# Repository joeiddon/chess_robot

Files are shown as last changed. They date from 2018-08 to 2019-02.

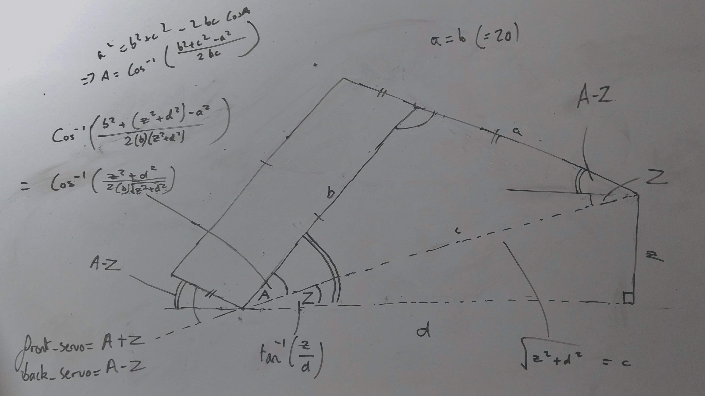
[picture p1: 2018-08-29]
calculations.jpg

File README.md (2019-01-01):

# Source for a full *chess-playing* robot.

*Note that this project is not finished.*

File/Directory|Purpose
----|---
[sketch/sketch.ino](sketch.ino)|Sketch for the Aruino Nano that controls the arm.
[vision.py](vision.py)|A (partial) computer vision library using `numpy` - only minimal functions.
[recognition.py](recognition.py)|Using `vision.py`, detects the locations of the pieces and identies their colours.
[tkinter_controller.py](tkinter_controller.py)|A GUI written with TKinter for controlling the robot arm.
[intelligence/](intelligence)|An AI written in C for finding the best chess move using [`negamax`](https://en.wikipedia.org/wiki/Negamax).
[model/](model)|Contains `.stl` and `.scad` designs for the 3d printed arm.

See some videos of the arm in progress here:

https://photos.app.goo.gl/uKwEp8JHDU8QnPrb8

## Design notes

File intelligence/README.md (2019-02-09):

chess_ai
========================

#### A Chess AI written in pure C. [work in progress]

An AI was originally written for this project in Python, however I made the mistake of describing my board state via a list which of course is mutable. As a result, I was forced to make lots of copies of the board state which severely reduced the speed of computation; resulting in an easily beatable player. Thus, I decided to start again from scratch at a lower level. This is that attempt.

---

### Navigating the Source

The code is split up into three `.c` source files: **`main.c`**, **`core.c`** and **`helpers.c`**.

 - The `main()` function is appropriately located in `main.c` and at the time of writing, merely has some different tests that can be commented in or out.
 - The `core.c` file contains the most algorithmically and computationally heavy functions (e.g. `generate_moves()` and `evaluate()`).
 - Handy functions, such as `display_state()` and `make_move()`, are found in `helpers.c`.

In addition to these, there are also three header files: **`common.h`**, **`core.h`** and **`helpers.h`**. The `common.h` header is `#include`d in every source file and contains `#define`s required by lots of functions and the main `struct`s. The `core.h` and `helpers.h` files are only included in their respective `.c` source files and the `main.c` source file.

---

### Compilation and Usage

To compile, use the following command.

```
gcc *.c -o chess_ai
```

The program can then be run with: `./chess_ai`.

---

### Code Explanation:

There are two main types (structures): `state_t` and `move_t` used throughout the code. (I appended the `_t` to make distinguish them from variable names).

In **`state_t`**, the state of the board is described by an `8` by `8` array of bytes (`int8_t`) named `pieces`. The array is described from white's perspective, with `(0,0)` at white's left castle. The magnitude of each element in the array determines the piece type, e.g. a bishop is represented by a `4` and the sign represents the side, positive for white and negative for black. An empty square is delineated by a zero. Their is also a member called `invalid_castles` which is a byte (`uint8_t`). It encodes which of the four possible castling moves are valid through its four least significant bits. Then, using bit-wise operators I wrote three macros to manipulate this variables bits: `GET_BIT(x,i)`, `SET_BIT_HIGH(x,i)` and `SET_BIT_LOW(x,i)`. Using these, we can now read and write to this member - resulting in a memory-efficient method to store which castling moves are valid.

The **`move_t`** structure has five members: `from`, `to`, `piece_taken`, `is_pawn_promotion`, `castle` and `makes_castle_invalid`. The `from` and `to` members are byte arrays (`uint8_t`), each of length 2. They hold the coordinates of the position the piece moved was picked up from, and placed at, respectively. The `piece_taken` member is a signed byte representing the piece taken with that move, if the move does result in a piece being taken, otherwise it holds `0`. This is required for the `inverse_move()` function, so the correct piece can be put back on the board. The `is_pawn_promotion` member is merely a boolean whose meaning is evident from its name. This member is again necessary for the `inverse_move` function to distinguish between a queen being moved by one vertically onto the back row and a legit pawn promotion. The `castle` member depicts whether the move is a castle, with a `0` implying not, a `1` implying a kingside castle and a `2` implying a queenside castle. Finally, the `makes_castle_invalid` member is a boolean representing if that move makes a castling no longer valid (illegal). You may ask: why is this necessary when you can just say in the `make_move()` function that whenever the king or a castle moves, the corresponding castle move(s) is/are now no longer valid? As before, this member is necessary for the `inverse_move()` function as in the case where the move describes a king or castle moving away from its home spot, it needs to be able to tell if this was the first move of that piece, or if it is merely a move later in the game when the piece re-visits the home spot. Hence, to be able to decide whether undoing this move makes it now legal to castle, the member is required to tell it if that specific move was the one that made it illegal (very long-winded, I know).

Now those two structures have been explained (in much detail), the code should be relatively easy to follow. Note that the `in_check` and `generate_moves` functions both use hacky macros, defined in `core.h`, that contain if-statements and `break` statements and span over multiple lines. They make those functions take at least half the line length they would be without them, but at the cost of making the code slightly unclear if you wish to follow what they do. Similarly, in the `make_move()` and `inverse_make()` functions, the macros `MOVE_TO` and `MOVE_FROM`, defined in `helpers.h`, make the code readable but are quite impure (hacky).

However, if I were to delve into the core of the code, I must explain the [Negamax algorithm](https://en.wikipedia.org/wiki/Negamax) and [Alpha-Beta pruning](https://en.wikipedia.org/wiki/Alpha%E2%80%93beta_pruning).

To explain negamax, un understanding of [minimax](https://en.wikipedia.org/wiki/Minimax) is required. This is an algorithm for deciding what is the best move to play in a given game. It works by depth-first searching the game tree, at each node, depending on whose turn it is, the algorithm tries to maximise or minimise the best score of all the moves that can be played from there. Since the game tree for chess cannot be traversed (the branching factor is `~30` and say that a game takes `~40` moves for each player, then there are `~30^80` possible states which is `~10^120` and there are only `~10^20` atoms in the observable universe), we must use an evaluation function to "rate" the current game position for a certain side once a given depth has been reached.

Negamax merely takes advantage of the fact that `max(x,y) = -min(-x,-y)`, so instead of having to write an if-statement to decide whether we should be maximising or minimising at a given stage, we can just always maximise the negative of the different move scores to decide our best move. This makes the basic algorithm really quite simple.

In pseudo-code:

```
If depth is 0:
    Return evaluation of current board

Otherwise...

Set our best move score to -infinity.
Loop through all possible moves
    Make that move
    If - opponents best score > best score:
        Set best move score to - opponents best score
        Set best move to current move
    Undo that move
End Loop

Return best move score
[...and somehow propagate up the corresponding best move]
```

Finally, there is room for a huge efficiency improvement. It's name, as previously mentioned, is alpha-beta pruning. I'll admit to it taking a while for me to fully understand its implementation but, with some thought, the following diagram should make it evident how certain portions of the tree can be "discounted" (not searched) - thus leading to less computation; allowing us to search to greater depths.

negamax and alpha-beta pruning image
*[source](https://commons.wikimedia.org/wiki/File:AB_pruning.svg)*

An example may also help. Say we have 2 moves to choose from: A and B. In doing move A, we see that our opponents best move ends up in us losing a pawn. Then mid-way though evaluating move B, we see that one of our opponents responses ends with us being a queen down. We now don't need to bother evaluating their other responses as we know that one of their replies results in an outcome worse than our current best outcome that we are assured of (just losing a pawn). Hence we don't need to evaluate these replies and can "prune" the game tree (all the two red lines in the diagram above).

Therefore, whenever we can assure that our best outcome is better than their best outcome (our worst), we can stop evaluating the current moves and return our best outcome.

This is coded by holding two variables: `alpha` and `beta` which represent our best and their best outcomes respectively. Then, we can say that whenever `alpha >= beta`, we can stop looping through our different moves (`break`/`return`). Since we are using negamax, when we pass these down to the next `negamax`, we must reverse them around - i.e. our best score is now the opponent's "opponent's best score" and their best score is now the opponent's "best score". Finally, we must negate both these values because they are trying to maximise their score.

This method leads to a major perfomance game. In the mid-game, the engine can search to depth `5` from the initial state in only about `1` second.

However, a very simple addition can be made to give us further advantages. This stems from the fact that the more of the tree we can prune earlier on, the faster are search is. We can prune more tree earlier on by doing some initial move ordering - taking a guess at what will be a good move. This function could be improved, but my current function `order_moves()` simply tells negamax which moves take pieces and which don't (very simple given our `move_t` data structure). Using this, these capture moves can be searched first - making prunes possible earlier.

The result of this initial move ordering is dramatic. It can now search to depth `6` from a complicated state (lots of captures, very congested) in just `1.5` seconds where the old algorithm took roughly `12` seconds for this!

My implementation for the negamax algorithm along with the simplistic `order_moves()` function can be found in **`core.c`**

### Limitations:

- No En-Passant.
- Auto queen-promotion for all pawns.
- No castling (I tried in [b5be2e8](https://github.com/joeiddon/chess_robot/commit/b5be2e8) but they're were so many bugs for little gain that I scrapped it).
- Get's into infinite loops when plays itself because no threefold repetition handling.

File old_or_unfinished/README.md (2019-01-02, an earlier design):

This sub-directory contains code that is not currently being used, but I am keeping to either:

- look back on for reference
- revisit in hope of completing it.

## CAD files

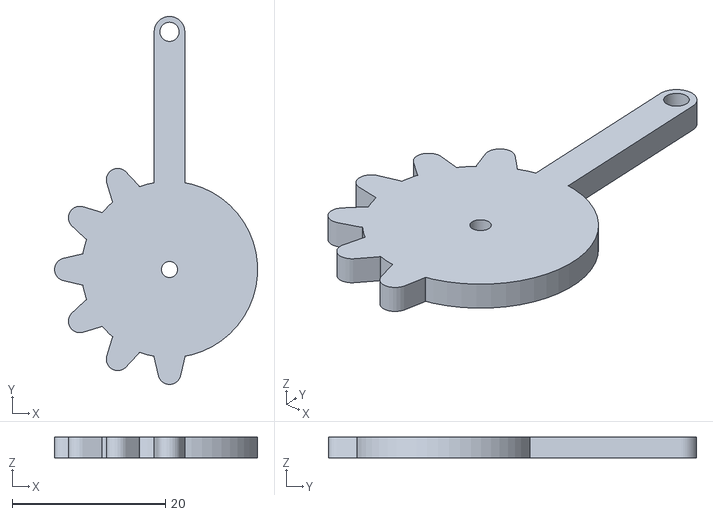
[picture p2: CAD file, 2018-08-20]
model/stls/gripper/right_gear.stl
26.5 x 48.0 x 2.70

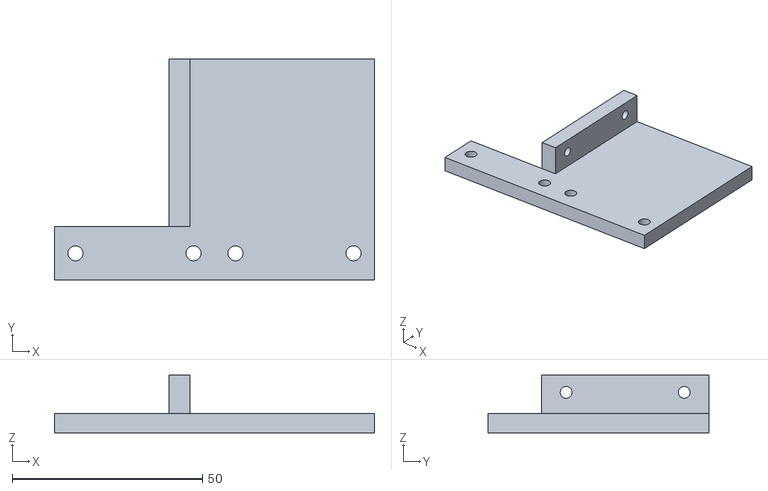
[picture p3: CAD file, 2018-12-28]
model/stls/stepper_plate.stl
84.0 x 58.0 x 15.1

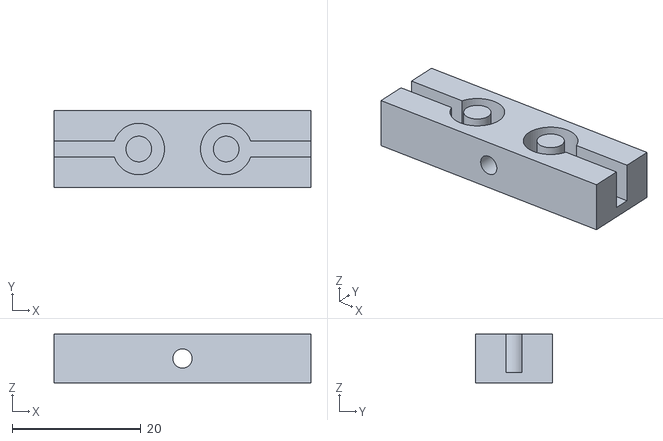
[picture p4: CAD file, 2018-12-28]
model/stls/belt_clamp.stl
40.0 x 12.0 x 7.60

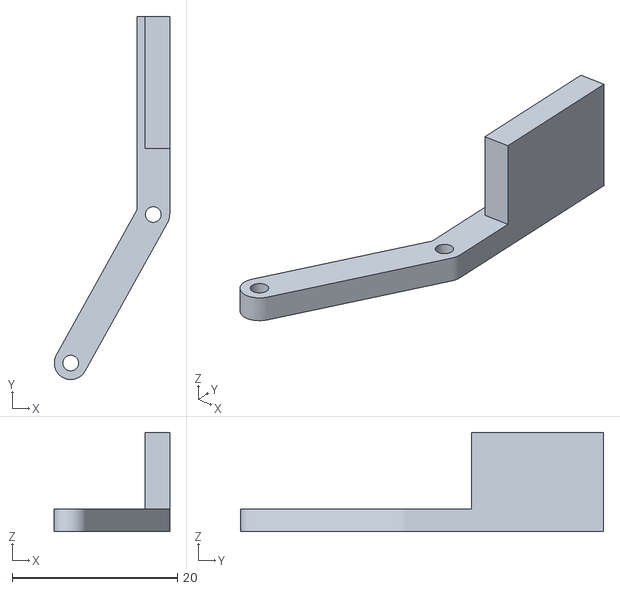
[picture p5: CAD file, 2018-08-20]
model/stls/gripper/left_arm.stl
14.0 x 44.0 x 12.0

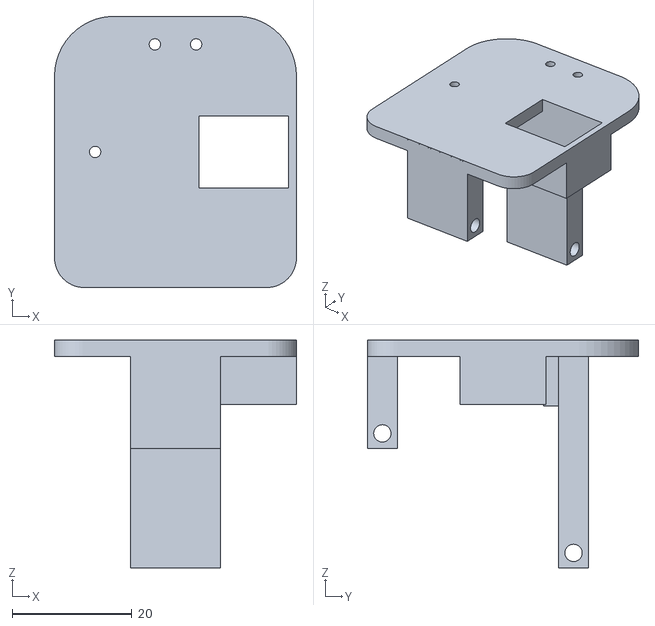
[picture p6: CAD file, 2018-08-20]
model/stls/gripper/bottom_plate.stl
40.5 x 45.4 x 38.1

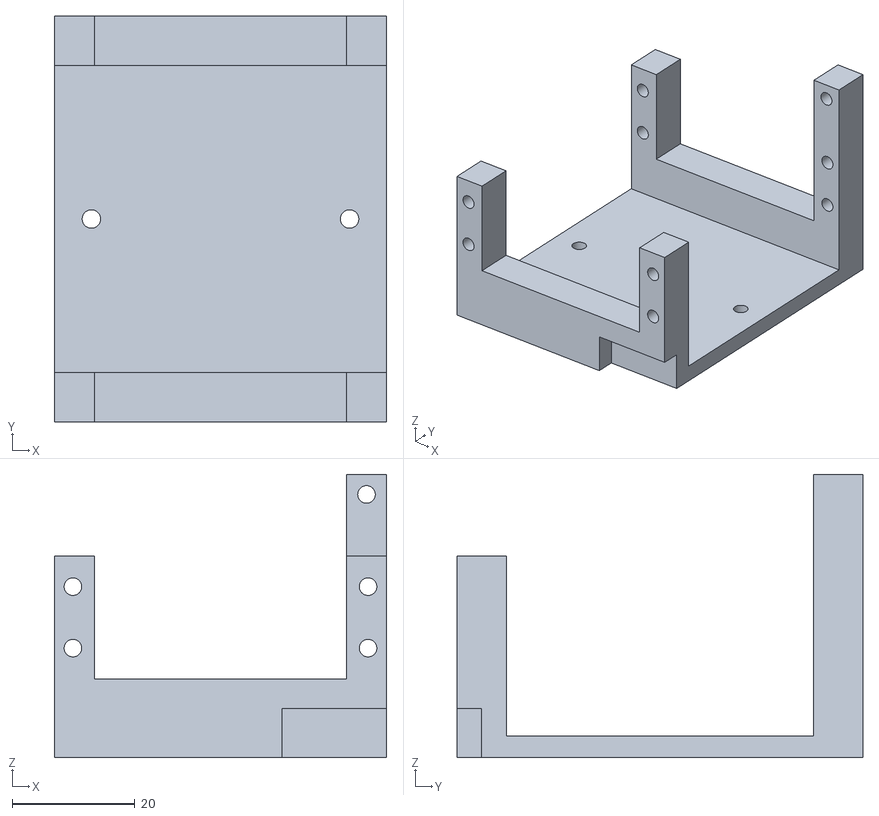
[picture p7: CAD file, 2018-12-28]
model/stls/plate.stl
54.0 x 66.0 x 46.0

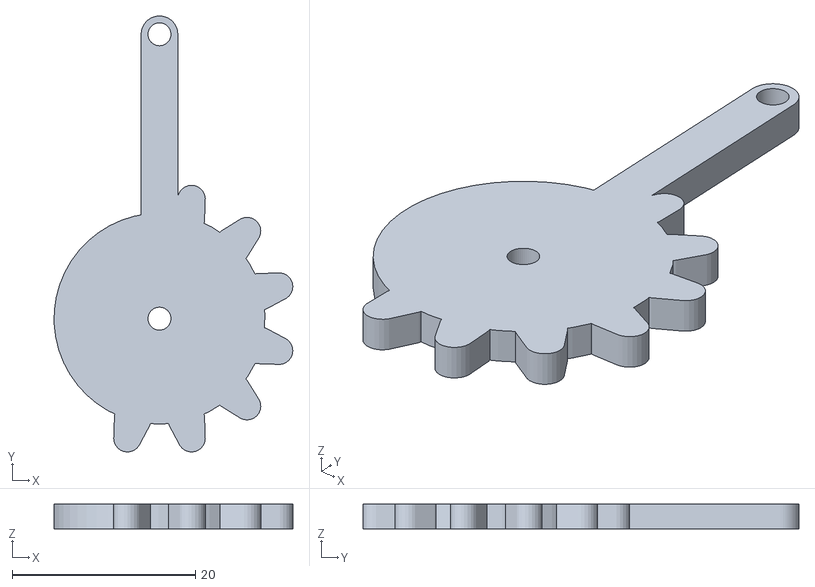
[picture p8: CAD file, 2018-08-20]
model/stls/gripper/left_gear.stl
26.0 x 47.5 x 2.70

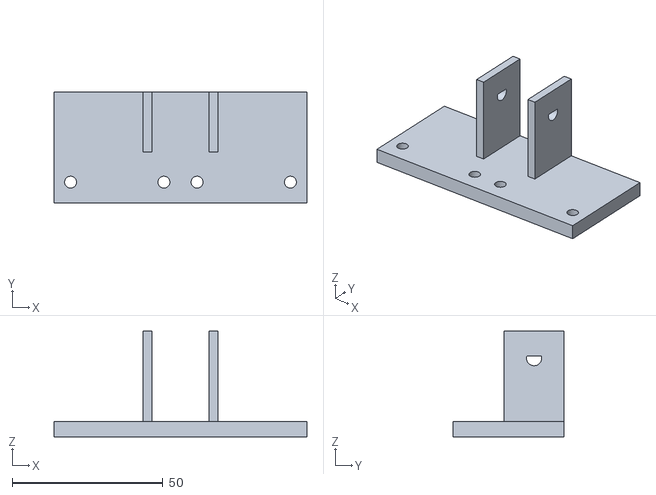
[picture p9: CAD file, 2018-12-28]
model/stls/pulley_plate.stl
84.0 x 37.0 x 35.1

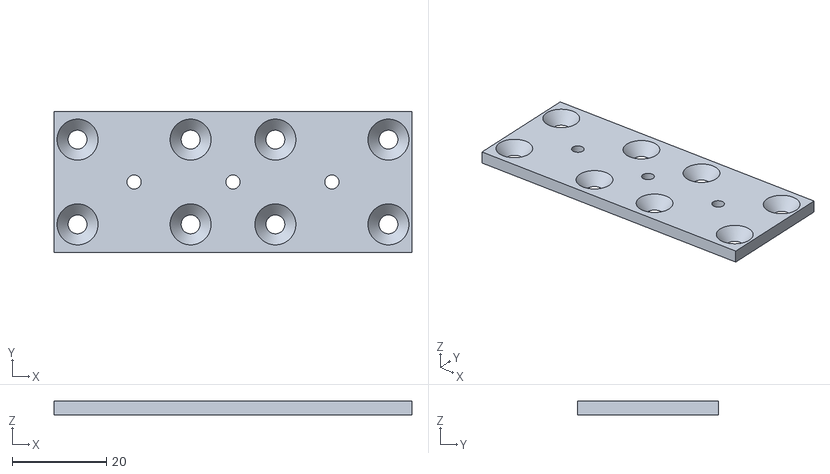
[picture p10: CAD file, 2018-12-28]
model/stls/bearing_plate.stl
76.0 x 30.0 x 3.00

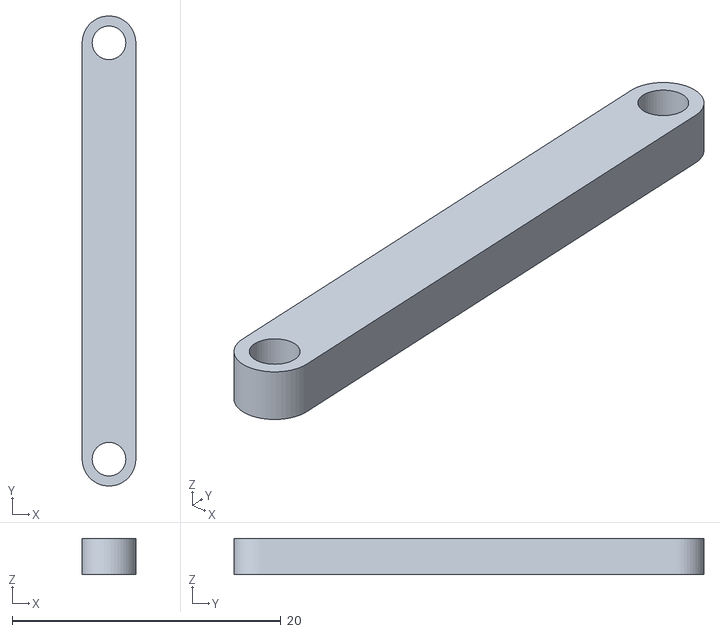
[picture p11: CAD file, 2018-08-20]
model/stls/gripper/beam.stl
4.00 x 35.0 x 2.70

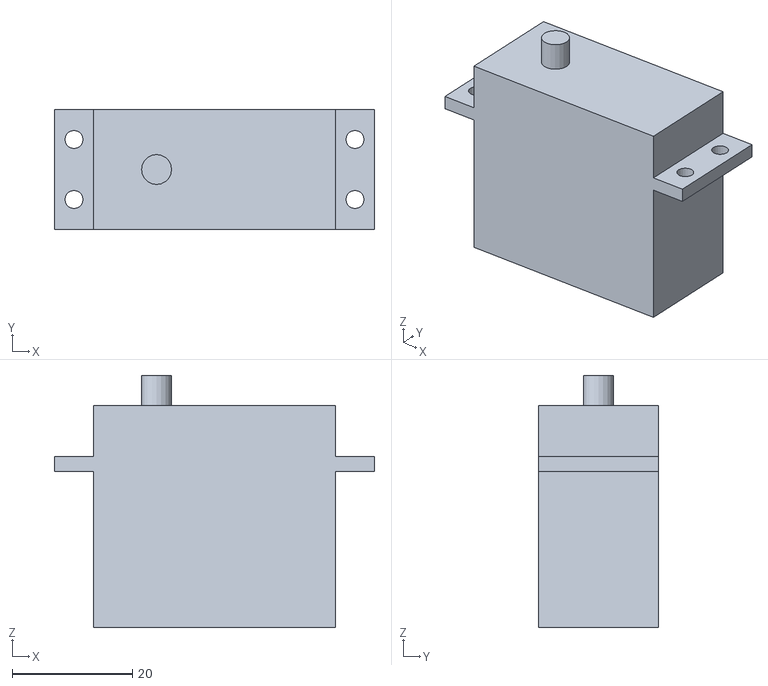
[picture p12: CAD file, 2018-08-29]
model/stls/mg996r.stl
53.3 x 20.0 x 42.0

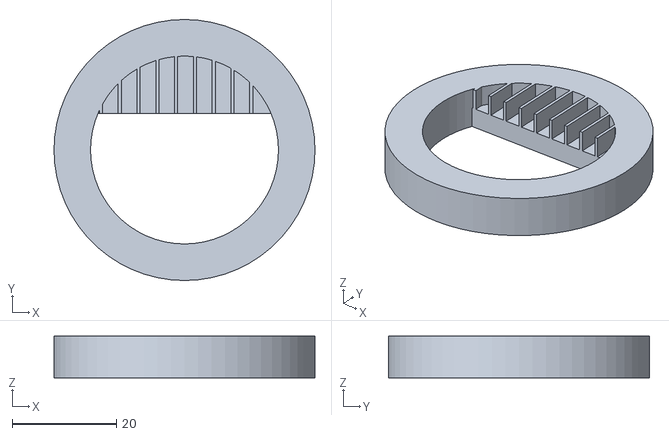
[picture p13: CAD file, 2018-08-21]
model/stls/ring.stl
50.0 x 50.0 x 8.00

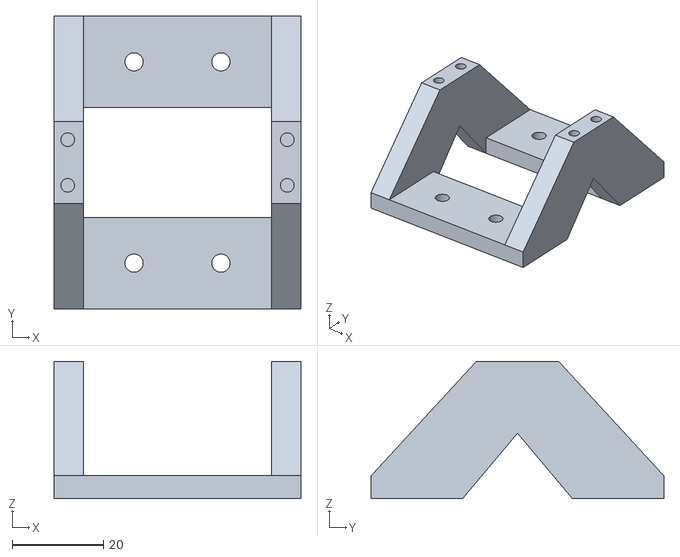
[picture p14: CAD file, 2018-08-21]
model/stls/base.stl
54.0 x 64.0 x 30.0

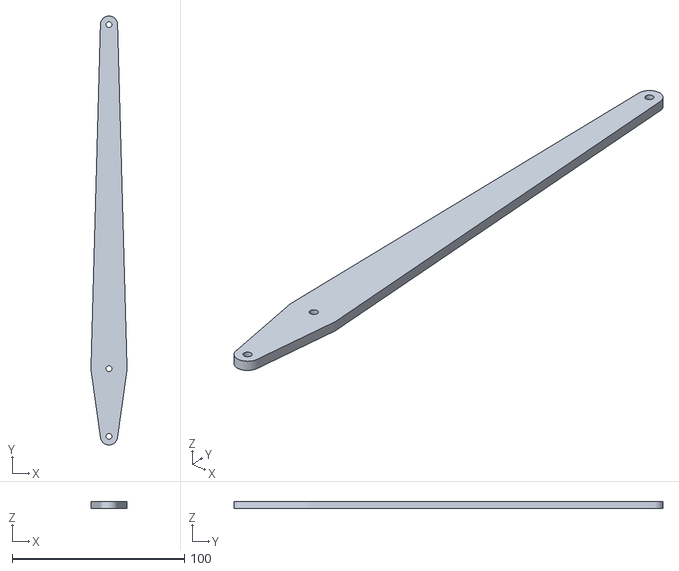
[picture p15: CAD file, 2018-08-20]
model/stls/link5.stl
21.0 x 249.4 x 3.90

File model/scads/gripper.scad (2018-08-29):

$fn = 50;
locked3mm = 2.9;           //hole diameter for a locked/tight/screwed down 2mm screw
free_turning2mm = 2.5;      //hole diameter for a free turning 2mm screw
locked2mm  = 1.9;            //hole diameter for a locked/tight/screwed down 2mm
thickness = 2.7;           //thickness of the gears and beams etc.
gear_radius = 15;           //radius of the gears (cogs)
left_gear_hole_diameter = free_turning2mm; //diameter of hole in left gear
right_gear_hole_diameter = 2.1;   //attacing to servo sotiny bit > 2mm (shrinkage)
no_teeth  = 7;              //number of teeth on the gears
teeth_width = 4;            //width of gear teeth
teeth_bevel = 3;            //diameter of circles at end of teeth
teeth_height = 3.5;         //height of gear teeth
teeth_budge = 0.4;         //distances gears need to be appart to fit together
beam_widths = 4;           //width of all beams
beam1_width = beam_widths;    //width of the first beam
beam1_length = 33;          //length of the first beam
beam1_hole_diameter = free_turning2mm; //diameter of screw hole at end of beam
beam2_width = beam_widths;   //width of the second beam
beam2_length = beam1_length; //length of the second beam
beam2_hole_diameter = free_turning2mm;//diameter of screw holes at end of beam
beam2_center_dist = 10;       //translating beam2 from beam1 towards the centerline
beam2_forward_dist = 18;     //translatimg beam2 from beam1 in y dir towards the grabber end
servo_width = 12;           //width of servo
servo_length = 23;          //length of servo
servo_height = 10.8;        //height of servo bracket (not whole servo)
servo_wall_thick = 1.2;      //thickness of bracket
servo_shaft = 5.9;          //distance of shaft from closest lengthwise edge
gripper_arm_length = 24;     //length of nipper
gripper_arm_thickness = 5;   //thickness of end nippers
gripper_arm_pad_length = 16;  //length of the raised pad
gripper_arm_pad_thickness = 3;//thickness of the raised pad
gripper_arm_pad_height = 12;  //height of the raised pad
gripper_arm_width = beam_widths; //width of end nippers

gear_hole_dist = gear_radius * 2 - teeth_height + teeth_budge;

//////

arm_block_width = 15;        //width of block for connecting arms
arm_block_length = 5;         //length ""
arm_block_height = 9.9 + 5.5;         //height for screws to attach to connecting arms

support_arm_length = 5;      //length of block
support_arm_width = 15;       //widhth of block
support_arm_height = arm_block_height + 20;     //heighrt for screw to attach to the support arm
support_arm_distance = 32;   //distance from little block
support_arm_stength_width  = 4;  //width of support for support arm block
support_arm_stength_length = 2.5; //length ""


plate_width = 40.5;           //width of bottom plate
plate_length = 40 + locked3mm + arm_block_length/2;          //length of bottom palte
plate_bevel_back = 5;        //bevel radius for back corners of plate
plate_bevel_front = 10;      //bevel radius for front corners of plate


module gear(){
   cylinder(r=gear_radius - teeth_height, h = thickness);
   for (i = [0:180/(no_teeth-1):180]){
      rotate(i)
      hull(){
         translate([0,-0.5*teeth_width,0])
         cube([gear_radius - teeth_height, teeth_width, thickness]);
         translate([gear_radius - teeth_bevel /2, 0, 0])
         cylinder(d = teeth_bevel, h=thickness, $fn = 25);
      }
   }
}


module left_gear(){
   difference(){
      union(){
         rotate(-(180/(no_teeth-1)) / 2 - 90)
         gear();
         beam1();
      }
      cylinder(d=left_gear_hole_diameter, h=thickness);
   }
}

module right_gear(){
   difference(){
      union(){
         rotate(90)
         gear();
         beam1();
      }
      cylinder(d=right_gear_hole_diameter, h=thickness);
   }  
}

module beam1(){
   difference(){
      union(){
         translate([-0.5 * beam1_width, 0, 0])
         cube([beam1_width, beam1_length - 0.5 * beam1_width, thickness]);
         translate([0, beam1_length - 0.5 * beam1_width, 0])
         cylinder(d=beam1_width, h=thickness);
      }
      translate([0, beam1_length - 0.5 * beam1_width, 0])
      cylinder(d=beam1_hole_diameter, h=thickness);
   }
}

module beam2(){
   difference(){
      union(){
         translate([-0.5 * beam2_width, 0, 0])
         cube([beam2_width, beam2_length - 0.5 * beam2_width, thickness]);
         cylinder(d=beam2_width, h=thickness);
         translate([0,beam2_length - 0.5 * beam2_width, 0])
         cylinder(d=beam2_width, h=thickness);   
      }
      cylinder(d=beam2_hole_diameter, h=thickness);
      translate([0, beam2_length - 0.5 *beam2_width, 0])
      cylinder(d=beam2_hole_diameter, h=thickness);      
   }
}

module bottom_plate(){
   difference (){
      //bottom base plate to cut crap out of
      hull(){
         translate([gear_hole_dist/2 - plate_width/2 + plate_bevel_front, plate_length/2 - plate_bevel_front, 0])
         cylinder(r=plate_bevel_front, h = thickness);
         translate([gear_hole_dist/2 + plate_width/2 - plate_bevel_front, plate_length/2 - plate_bevel_front, 0])
         cylinder(r=plate_bevel_front, h = thickness);
         translate([gear_hole_dist/2 - plate_width/2 + plate_bevel_back , -plate_length/2 + plate_bevel_back, 0])
         cylinder(r=plate_bevel_back, h = thickness);
         translate([gear_hole_dist/2 + plate_width/2 - plate_bevel_back , -plate_length/2 + plate_bevel_back, 0])
         cylinder(r=plate_bevel_back, h = thickness);
      }
      
      /*
      translate([-0.5 * plate_length + 0.5 * gear_hole_dist, -0.5 * plate_width, 0])
      cube([plate_length, plate_width, thickness]);
      */
      
      //holes for screws of gears and servo mount cutouts
      cylinder(d=locked2mm,h=thickness);
      translate([gear_hole_dist -2, 0, 0])
      cube([15, servo_width, 30], center=true);  
      
      //cutouts for beam 2 bottom hole mounts
      translate([beam2_center_dist, beam2_forward_dist, 0])
      cylinder(d=locked2mm, h=thickness);
      translate([gear_hole_dist - beam2_center_dist, beam2_forward_dist, 0])
      cylinder(d=locked2mm, h=thickness);
      
   }
   translate([gear_hole_dist, 0, -servo_height + thickness])
   servo_bracket();
   
   //arm block
   translate([gear_hole_dist / 2 - arm_block_width/2, -plate_length/2, -arm_block_height])
   difference(){
      cube([arm_block_width, arm_block_length, arm_block_height + arm_block_length/2]);
      translate([0, arm_block_length/2, arm_block_length/2 ])
      rotate([0, 90, 0])
      cylinder(d = locked3mm, h=arm_block_width);
   }
   
   //suport arm block
   translate([gear_hole_dist / 2 - support_arm_width/2, -plate_length/2 + arm_block_length/2 + support_arm_distance - support_arm_length/2, -support_arm_height])
   difference(){
      union(){
         cube([support_arm_width, support_arm_length, support_arm_height + support_arm_length/2]);
         translate([support_arm_width/2-support_arm_stength_width/2,-support_arm_stength_length,support_arm_length/2+ support_arm_height - servo_height])
         cube([support_arm_stength_width, support_arm_stength_length, servo_height]);
      }
      translate([0,support_arm_length/2, support_arm_length/2])
      rotate([0, 90, 0])
      cylinder(d=locked3mm, h = support_arm_width);
   }
         
}

module servo_bracket(){
 translate([-(servo_length+2*servo_wall_thick)/2 - servo_shaft,-(servo_width+2*servo_wall_thick)/2,0])
 difference(){
   cube([servo_length + 2*servo_wall_thick, servo_width + 2*servo_wall_thick, servo_height]);
   translate([servo_wall_thick, servo_wall_thick, 0])
   cube([servo_length, servo_width, servo_height]);
 }   
}

module gripper_arm(){
   difference(){
      union(){
         hull(){
            cylinder(d = gripper_arm_width, h = thickness);   
            translate([beam2_center_dist, beam2_forward_dist, 0])
            cylinder(d = gripper_arm_width, h = thickness);
         }
         translate([-0.5 * gripper_arm_width + beam2_center_dist, beam2_forward_dist, 0])
         cube([gripper_arm_width, gripper_arm_length, thickness]);

         translate([-0.5 * gripper_arm_width + beam2_center_dist + (gripper_arm_width - gripper_arm_pad_thickness), beam2_forward_dist + (gripper_arm_length - gripper_arm_pad_length), 0])
         cube([gripper_arm_pad_thickness, gripper_arm_pad_length, gripper_arm_pad_height]);
         
      }
      cylinder(d = locked2mm, h = thickness);   
      translate([beam2_center_dist, beam2_forward_dist, 0])
      cylinder(d = locked2mm, h = thickness);
      
   }
}

module left_arm(){
   gripper_arm();
}

module right_arm(){
   mirror([1,0,0])
   gripper_arm();
}


translate([0,beam1_length - 0.5 * beam_widths,-thickness])
left_arm();

translate([gear_hole_dist,beam1_length - 0.5 * beam_widths,-thickness])
!right_arm();

translate([beam2_center_dist,beam2_forward_dist,0])
beam2();

translate([gear_hole_dist - beam2_center_dist,beam2_forward_dist,0])
beam2();


translate([0,0,-thickness])
bottom_plate();

left_gear();
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

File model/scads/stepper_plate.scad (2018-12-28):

$fn=60;
plate_width = 58;
plate_length = 84;
thickness = 5.1;
support_hole_diameter = 3.95;
support_hole_dist = 31;
support_hole_edge_dist = 7;
support_width = 14; //used for cutout for stepper
stepper_hole_dist = 31;
stepper_hole_diameter = 3.1;
stepper_support_height = 10;
stepper_support_width = 5.6;
stepper_hole_height = 5.5;
stepper_edge_cut = 30;


module stepper_support(){
    difference(){
        cube([stepper_support_width, plate_width - support_width, stepper_support_height]);
        translate([0, (plate_width - support_width + stepper_hole_dist) / 2, stepper_hole_height])
        rotate([0, 90, 0])
        cylinder(d=stepper_hole_diameter,  h=stepper_support_width);
        translate([0, (plate_width - support_width - stepper_hole_dist) / 2, stepper_hole_height])
        rotate([0, 90, 0])
        cylinder(d=stepper_hole_diameter,  h=stepper_support_width);
    }
}

module support_holes(){
    translate([plate_length/4 - support_hole_dist/2, support_hole_edge_dist, 0]){
        cylinder(d=support_hole_diameter, h=thickness);
        translate([support_hole_dist, 0, 0])
        cylinder(d=support_hole_diameter, h=thickness);
    }
    translate([3*plate_length/4 - support_hole_dist/2, support_hole_edge_dist, 0]){
        cylinder(d=support_hole_diameter, h=thickness);
        translate([support_hole_dist, 0, 0])
        cylinder(d=support_hole_diameter, h=thickness);
    }
}

difference(){
    union(){
        cube([plate_length, plate_width, thickness]);
        translate([stepper_edge_cut, support_width, thickness])
        stepper_support();
    }
    support_holes();
    translate([0,  support_width, 0])
    cube([stepper_edge_cut, plate_width - support_width, thickness]);
}

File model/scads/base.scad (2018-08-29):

//general
$fn = 30;                        //convexity of general curved faces
thickness = 5;                   //thickness of the flat parts
length = 54;

//bottom plate (feet)
plate_hole_diameter = 4;            //diameter of holes in metal bottom plate
plate_hole_width = 19;             //shortest distance between the pairs of holes in plate
plate_hole_length = 44;            //long distance between the pairs of holes in botto
plate_feet_width = 20;             //width of the pads that connect the short distanced screws
plate_feet_length = length;            //length of the feet
//servo pad
servo_hole_diameter = 3;           //diamter of holes for servo attachment
servo_hole_width = 10;             //width of short distance between hole so same side of servo
servo_hole_length = 48;            //length of long distance between holes on either side of servo
servo_pad_width = 18;              //width of servo pad
servo_pad_length = length;         //length of servo pad
servo_pad_height = 25;             //height of servo pad
servo_length = 41;

module foot(){
   translate([0, plate_feet_width/-2, 0])
   difference(){
      cube([plate_feet_length, plate_feet_width, thickness]);
      translate([plate_feet_length/2 - plate_hole_width/2, plate_feet_width/2, 0])
      cylinder(h=thickness, d=plate_hole_diameter);
      translate([plate_feet_length/2 + plate_hole_width/2, plate_feet_width/2, 0])
      cylinder(h=thickness, d=plate_hole_diameter);
   }
}


module servo_pad(){
   difference(){
      cube([servo_pad_length, servo_pad_width, thickness]);
      translate([servo_pad_length/2 - servo_hole_length/2, servo_pad_width/2 - servo_hole_width/2, 0])
      cylinder(d = servo_hole_diameter, h = thickness);
      translate([servo_pad_length/2 - servo_hole_length/2, servo_pad_width/2 + servo_hole_width/2, 0])
      cylinder(d = servo_hole_diameter, h = thickness);
      translate([servo_pad_length/2 + servo_hole_length/2, servo_pad_width/2 - servo_hole_width/2, 0])
      cylinder(d = servo_hole_diameter, h = thickness);
      translate([servo_pad_length/2 + servo_hole_length/2, servo_pad_width/2 + servo_hole_width/2, 0])
      cylinder(d = servo_hole_diameter, h = thickness);
   }   
}

module wall(){
   hull(){
      translate([0,plate_feet_width/-2, 0])
      cube([plate_feet_length, plate_feet_width, thickness]);
      translate([0,plate_hole_length/2 - servo_pad_width/2, servo_pad_height])
      cube([servo_pad_length, servo_pad_width, thickness]);
   }  
}

module base(){
    difference(){
       union(){
          difference(){
             union(){
                wall();
                translate([0, plate_hole_length, 0])
                mirror([0,1,0])
                wall();
             }
             translate([0, plate_hole_length/2 - servo_pad_width/2, servo_pad_height])
             cube([servo_pad_length, servo_pad_width, thickness]);
          }
          translate([0, plate_hole_length/2 - servo_pad_width/2, servo_pad_height])
          servo_pad();
       }
       translate([(length - servo_length) / 2 ,-0.5 * plate_hole_length, 0])
       cube([servo_length, plate_hole_length*2, servo_pad_height * 2]);   
    }

    foot();
    translate([0, plate_hole_length, 0])
    foot();
}

base();

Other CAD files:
model/stls/gripper/right_arm.stl
model/stls/link7.stl
model/stls/link2.stl
model/stls/link4.stl
model/scads/bearing_plate.scad
model/scads/belt_clamp.scad
model/scads/link1.scad
model/scads/link2.scad
model/scads/link3.scad
model/scads/link4.scad
model/scads/link5.scad
model/scads/link6.scad
model/scads/link7.scad
model/scads/mg996r.scad
model/scads/plate.scad
model/scads/pulley_plate.scad
model/stls/link1.stl
model/stls/link3.stl
model/stls/link6.stl

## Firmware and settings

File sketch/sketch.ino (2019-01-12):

#include <Servo.h>

/*
 Prerequisites:
  - all distances are in *millimeters*

  TODO:
    - right better explanation for program here
    - add checks to move_to assert the inputs are valid
 
==Polulo A4988 Mode Selection==
  MS1 | MS2 | MS3 | Resolution
  0   | 0   | 0   | Full
  1   | 0   | 0   | Half
  0   | 1   | 0   | Quarter
  1   | 1   | 0   | Eighth
  1   | 1   | 1   | Sixteenth

==Joe's Serial Protocol==
  Runs at a baud rate of 115200 pulses per second.
  The number of bytes in the message is sent first.
  The next byte represents the message type.
  The following number of enclosed bytes (NEBs) is dependent on the message type.
  First byte  | Message (type)  | NEBs | Enclosed bytes meaning
  0           | home            | 0    | N/A
  1           | motor state     | 1    | (0/1 => disable/enable)
  2           | set grabber     | 1    | (0/1 => grab off/grab on
  3           | move position   | 6    | (x: [0¬335, y: [100¬450], z: [0¬200])
                                          ^          ^             ^
       these uint16s (actually casted to signed) are sent *little-endian* (see INT_FROM_BYTES)

  Arduino will reply with a one byte code after every message.
  Value       | Meaning
  0           | Task completed as expected
  1           | x_pos has reached x_target - useful for timings
  2           | Invalid request structure (wrong NEBs)
  3           | Task failed due to invalid input ranges
  4           | Unkown request type

==Debugging Random Stepper Movements==
 -check STEP_SPEED
 -check motors are enabled (enable_motors called before x_pos set)

*/

//pin definitions
#define STEPPER_ENABLE 2
#define STEPPER_DIR    3
#define STEPPER_STEP   4
#define ENDSTOP        5
#define SERVOS_ENABLE  6
#define SERVO_BACK     7
#define SERVO_FRNT     8
#define SERVO_GRABBER  9

//servo offsets (microseconds pulse widths)
#define SERVO_OFFSET_FRNT -240
#define SERVO_OFFSET_BACK -640

//grabber position in pulse widths
#define SERVO_GRAB_POS_ON   2150
#define SERVO_GRAB_POS_OFF  1940

//relevant dimensions of arm
//GRIPPER_HEIGHT must be less than PIVOT_HEIGHT as using unsigned
#define SEGMENT_LENGTH_1 200
#define SEGMENT_LENGTH_2 200
#define GRIPPER_HEIGHT   50  //missed this in the old version!
#define GRIPPER_LENGTH   35
#define PIVOT_HEIGHT     60  //servo pivot height from ground

//stepper direction macros
#define LEFT  1
#define RIGHT 0
//full-half-quater-eigth-or-sixteenth-step
#define STEP_MODE 16
//how far does the belt move per step?
#define STEP_DIST 0.15798
//speeds are delays in microseconds between each full step
#define MAX_STEP_SPEED 1000
#define MIN_STEP_SPEED 2800  //<<< keep this low, accel_pulse_us array only bytes
//acceleration and deceleration will take this many millimeters
#define ACCEL_AND_DECELERATION_DIST  15

//number of sub-steps for acceleration and deceleration
#define NUM_ACCEL_OR_DECEL_STEPS (uint16_t) (ACCEL_AND_DECELERATION_DIST / STEP_DIST * STEP_MODE)

//predefined arm positions
//servo home position:  d,  z
#define SERVO_HOME    180,100
#define X_IN_RANGE(x)   0<=(x) && (x)<=335
#define Y_IN_RANGE(y) 100<=(y) && (y)<=450
#define Z_IN_RANGE(z)   0<=(z) && (z)<=200

//serial
#define BUF_LENGTH 7
#define INT_FROM_BYTES(A, B) (int16_t) ((A)<<8)+(B)
#define CODE_NORMAL           0
#define CODE_X_TARGET_REACHED 1
#define CODE_INVALID_NEBS     2
#define CODE_INVALID_INPUT    3
#define CODE_INVALID_TYPE     4

//initialise servo objects
Servo servo_back;
Servo servo_frnt;
Servo servo_grabber;

//x current and target postions are steps (or sub-steps) from home.
//uint16_t big enough as max x / STEP_DIST * 16 < 65536 (max)
uint16_t x_pos;
uint16_t x_target;

//set to 0 every time we move so we know when to stop accelerating
uint16_t pulses_since_accel_start;
//array to store accel/decel pulse lengths as they take too long
//to calculate on the fly, so computed in setup() and stored
uint8_t  accel_pulse_us[NUM_ACCEL_OR_DECEL_STEPS / STEP_MODE + 1];
//^ only single bytes, so don't go for crazy large pulses as will overflow!

//timings for pulses (us == microseconds)
uint32_t last_pulse_us; //initialised in go_home();
uint16_t pulse_interval_us;

//serial
uint8_t serial_buffer[BUF_LENGTH];
uint8_t msg_bytes = 0;
uint8_t buf_pointer = 0;

//experimental/debug variables
#define DEBUG_MODE 0
uint16_t counter = 0;

void setup() {
    //attach servo objects to their pins, setting end widths
    servo_back.attach(SERVO_BACK, 500, 2500);
    servo_frnt.attach(SERVO_FRNT, 500, 2500);
    servo_grabber.attach(SERVO_GRABBER, 500, 2500);
    //set modes of all digital pins
    pinMode(STEPPER_ENABLE, OUTPUT);
    pinMode(STEPPER_DIR,    OUTPUT);
    pinMode(STEPPER_STEP,   OUTPUT);
    pinMode(ENDSTOP,        INPUT);
    pinMode(SERVOS_ENABLE,  OUTPUT);
    //debug LED
    pinMode(13, OUTPUT);
    //connect to our master
    Serial.begin(115200);

    for (uint16_t i = 0; i < NUM_ACCEL_OR_DECEL_STEPS / STEP_MODE + 1; i++){
        accel_pulse_us[i] = smootherstep_interp((float) i / (NUM_ACCEL_OR_DECEL_STEPS / STEP_MODE),
                                          MIN_STEP_SPEED, MAX_STEP_SPEED) / STEP_MODE;
    }

    go_home();
}

void loop() {
    //no blocking functions allowed, this needs to zip
    //around as fast as possible for the stepper steps
    if (Serial.available()){
        uint8_t b = Serial.read();
        if (msg_bytes){ //we are mid-message...
            serial_buffer[buf_pointer++] = b;
            if (buf_pointer == msg_bytes){
                handle_message();
                msg_bytes = 0;
            }
        } else { //first byte of a message...
            msg_bytes = b;
            buf_pointer = 0;
        }
    }
    //if not at stepper target and due to pulse, let's pulse
    if (x_pos != x_target && (micros() - last_pulse_us) >= pulse_interval_us){
        if (DEBUG_MODE && !(counter++ & 0xff)){
            Serial.print(0); Serial.print(" "); Serial.print(300); Serial.print(" ");
            Serial.println(pulse_interval_us);
        }
        //make it look like we pulsed at the right time
        last_pulse_us += pulse_interval_us;
        //pulse the motor
        step_stepper(x_pos < x_target ? RIGHT : LEFT);

        //adjust pulse_interval_us according to if decelerating or accelerating
        uint16_t steps_from_target = x_pos < x_target ? x_target - x_pos : x_pos - x_target;
        if (x_target == 0){
            pulse_interval_us = MIN_STEP_SPEED / STEP_MODE;
        } else if (steps_from_target < NUM_ACCEL_OR_DECEL_STEPS){
            //decelerating
            if (steps_from_target < pulses_since_accel_start)
            pulse_interval_us = accel_pulse_us[steps_from_target / STEP_MODE];
            else
            pulse_interval_us = MIN_STEP_SPEED / STEP_MODE;
        } else if (pulses_since_accel_start < NUM_ACCEL_OR_DECEL_STEPS){
            //accelerating
            pulse_interval_us = accel_pulse_us[pulses_since_accel_start++ / STEP_MODE];
        }
        //if going home, we listen for endstop instead of blindly moving :)
        if (x_target == 0){
            if (digitalRead(ENDSTOP)){
                x_pos = 0;
                Serial.write(CODE_X_TARGET_REACHED);
                //this is just so that the arm doesn't wait on the endstop as it is drying
                x_target = 500;
           }
        } else {
            x_pos += x_pos < x_target ? 1 : -1;
            if (x_pos == x_target)
            Serial.write(CODE_X_TARGET_REACHED);
       }
    }
}

//these interpolation functions are for smoothing the acceleration
//only one is actually used to populate the accel_pulse_us array
uint16_t linear_interp(float x, int16_t a, int16_t b){
    //basic linear, x in range [0¬1]
    return a + x * (b - a);
    // ^ ~20us so fast enough to calculate on fly
}

uint16_t smoothstep_interp(float x, int16_t a, int16_t b){
    //3x^2 - 2x*3
    return a + (3*x*x - 2*x*x*x) * (b - a);
    // ^ ~80us to complete! too slow to calculate on fly
}

uint16_t smootherstep_interp(float x, int16_t a, int16_t b){
    //6x^5 - 15x^4 + 10x^3
    return  a + (6*x*x*x*x*x - 15*x*x*x*x + 10*x*x*x) * (b - a);
    // ^~142us to complete! too slow to calculate on fly
}

void handle_message(){
    switch (serial_buffer[0]){
        case 0: //home
            if (msg_bytes == 1){
                Serial.write(CODE_NORMAL);
                go_home();
            } else {
                Serial.write(CODE_INVALID_NEBS);
            } break;
        case 1: //set motors
            if (msg_bytes == 2){
                if (serial_buffer[1]) enable_motors();
                else disable_motors();
                Serial.write(CODE_NORMAL);
            } else {
                Serial.write(CODE_INVALID_NEBS);
            } break;
        case 2: //set grabber
            if (msg_bytes == 2){
                Serial.write(CODE_NORMAL);
                set_grabber(serial_buffer[1]);
            } else {
                Serial.write(CODE_INVALID_NEBS);
            } break;
        case 3: //move to
            if (msg_bytes == 7){
                int16_t x = INT_FROM_BYTES(serial_buffer[1], serial_buffer[2]),
                        y = INT_FROM_BYTES(serial_buffer[3], serial_buffer[4]),
                        z = INT_FROM_BYTES(serial_buffer[5], serial_buffer[6]);
                if (X_IN_RANGE(x) && Y_IN_RANGE(y) && Z_IN_RANGE(z)){
                    Serial.write(CODE_NORMAL);
                    move_to(x,y,z);
                } else {
                    Serial.write(CODE_INVALID_INPUT);
                }
            } else {
                Serial.write(CODE_INVALID_NEBS);
            } break;
        default:
            Serial.write(CODE_INVALID_TYPE);
            break;
    }
}

void move_to(int16_t x, int16_t y, int16_t z){
    //move to position (x,y,z), limits are described by the *_IN_RANGE(*) macros
    //right-handed co-ordinate system, orientated:
    // - x-axis is stepper; measured from home
    // - y-axis is horizontally perpendicular towards the gripper; measured from servo pivots
    // - z-axis is, therefore, vertical; measured from the ground
    //enable motors, in case not already
    enable_motors();
    //move servos
    move_servos(y, z);
    //convert x coordinate in mm to steps, and set as target
    x_target = x / STEP_DIST * STEP_MODE;
    //if already there, send appropriate reply
    if (x_pos == x_target) Serial.write(CODE_X_TARGET_REACHED);
    //need to pretend we just pulsed so timeings re-baised from here
    last_pulse_us = micros();
    pulses_since_accel_start = 0;
}

void move_servos(int16_t d, int16_t z){
    //[modulised as used when homing too]
    //moves the front and back servos to their correct angles
    //see get_servo_angles for meaning of parameters
    float angles[2];
    get_servo_angles(d, z, angles);
    //write angles: offset, map to pulse widths whilst fixing direction
    servo_back.writeMicroseconds(2500 - angles[0] * (2000 / PI) + SERVO_OFFSET_BACK);
    servo_frnt.writeMicroseconds(2500 - angles[1] * (2000 / PI) + SERVO_OFFSET_FRNT);
}

void get_servo_angles(int16_t d, int16_t z, float angles_out[2]) {
    //d is horizontal distance of gripper from base
    //z is veritcal distance (height) of gripper from base
    //servo angles => angles_out = [back_angle, front_angle] in radians
    //see image in repo for calculations reference (meaning of letters)
    d -= GRIPPER_LENGTH; //don't need to go as far as gripper has length
    z += GRIPPER_HEIGHT; //need to go higher as gripper has height
    z -= PIVOT_HEIGHT;   //don't need to go as high as servo pivots already in air
    d -= GRIPPER_LENGTH; //don't need to go as far as gripper has length
    float Z = atan2(z, d);
    float A = acos((sq((int32_t)SEGMENT_LENGTH_1) + sq((int32_t)d) + sq((int32_t)z) - sq((int32_t)SEGMENT_LENGTH_2)) /
                   (2 * SEGMENT_LENGTH_1 * sqrt(sq((int32_t)d) + sq((int32_t)z))));
    float B = acos((sq((int32_t)SEGMENT_LENGTH_2) + sq((int32_t)d) + sq((int32_t)z) - sq((int32_t)SEGMENT_LENGTH_1)) /
                   (2 * SEGMENT_LENGTH_2 * sqrt(sq((int32_t)d) + sq((int32_t)z))));
    angles_out[0] = B - Z;
    angles_out[1] = A + Z;
}

void go_home(){
    //mainly self-explanatory...
    enable_motors();
    move_servos(SERVO_HOME);
    set_grabber(0);
    x_pos = 1;    //tricks pulsing code into moving
    x_target = 0; //special case in pulsing code
    last_pulse_us = micros();
    pulses_since_accel_start = 0;
}

void step_stepper(uint8_t dir){
    digitalWrite(STEPPER_DIR, dir);
    digitalWrite(STEPPER_STEP, LOW);
    digitalWrite(STEPPER_STEP, HIGH);
}

void enable_motors(){
    digitalWrite(SERVOS_ENABLE,  HIGH);
    digitalWrite(STEPPER_ENABLE, LOW);
}

void disable_motors(){
    digitalWrite(SERVOS_ENABLE,  LOW);
    digitalWrite(STEPPER_ENABLE, HIGH);
}

void go_offset_calibration(){
    servo_frnt.writeMicroseconds(1500 + SERVO_OFFSET_FRNT);
    servo_back.writeMicroseconds(2500 + SERVO_OFFSET_BACK);
}

void set_grabber(uint8_t state){
    //state is 1/0 indicating grab on/grab off
    servo_grabber.writeMicroseconds(state ? SERVO_GRAB_POS_ON : SERVO_GRAB_POS_OFF);
}

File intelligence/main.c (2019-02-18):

#include <stdio.h>
#include <stdint.h>
#include <string.h>

#include "common.h"
#include "core.h"
#include "helpers.h"

//see git commit history for some other pre-typed-out states
//standard start start
state_t state = {{{ ROOK,  KNIGHT,  BISHOP,  QUEEN,  KING,  BISHOP,  KNIGHT,  ROOK},
                  { PAWN,    PAWN,    PAWN,   PAWN,  PAWN,    PAWN,    PAWN,  PAWN},
                  {    0,       0,       0,      0,     0,       0,       0,     0},
                  {    0,       0,       0,      0,     0,       0,       0,     0},
                  {    0,       0,       0,      0,     0,       0,       0,     0},
                  {    0,       0,       0,      0,     0,       0,       0,     0},
                  {-PAWN,   -PAWN,   -PAWN,  -PAWN, -PAWN,   -PAWN,   -PAWN, -PAWN},
                  {-ROOK, -KNIGHT, -BISHOP, -QUEEN, -KING, -BISHOP, -KNIGHT, -ROOK}}};
                  /*
state_t state = {{{    0,       0,       0,      0,     0,  KING,       0,     0},
                  {    0,       0,       0,      0,     0,       0,       0,    0},
                  {    0,       0,       0,      0,     0,       0,       0,    0},
                  {    0,       0,       0,      0,     0,       0,       0,     0},
                  {    0,       0,       0,      0,     0,       0,       0,     0},
                  {    0,       0,       0,      0,     0,       0,       0,     0},
                  {-ROOK,       0,   -ROOK,      0,     0,       0,       0,     0},
                  //{    0,       0,       0,      0, -KING,       0,       0,     0}}};
                  //{    0, KNIGHT, -BISHOP, -QUEEN, -KING, -BISHOP, -KNIGHT, -ROOK}}};
                  {    0,       0,       0,      0, -KING,       0,       0,     0}}};
                  */

void main(int argc, char** argv){
    /* Mode of operation:
     *  Make-one-move mode is entered if there are any command line arguments.
     *  Otherwise, a terminal-bsaed game is begun.
     *
     * The format for the command line arguments is decribed below in the
     * "cmd-line make-one-move" section. In this mode, a board state (and other info)
     * is parsed, and the program writes to stdout the best move it can come up with.
     * Or, if a different type is sent, it will return some info.
     *
     * In the terminal-based game mode, ingo (e.g. the current state of the board) and
     * prompts are written to stdout, allowing one to play a game in the terminal.
     *
     * Finally, there are some commented out debugging calls left at the bottom for
     * when something isn't working right (e.g. castling at the moment [removed completely
     * now]) and specific things need testing.
     */

    if (argc > 1){

        ///////////////////////CMD-LINE MAKE-ONE-MOVE///////////////////////////////////////////

        //begin code for cmd line make-one-move mode
        /* ---Interface---
         *
         * The first argument is the board:
         *   - board state: a 64 character string of piece chars (upper is white, lower is black).
         * The second argument indicates the side:
         *   - side: "white" or "black".
         * The third argument is the type of request:
         *   - type: "eval" or "move".
         *
         * If the type is "eval", then no further arguments are required.
         * In this case, three values are returned:
         *      - checkmate status: is "side" checkmated ? 1 or 0;
         *      - evaluation of state: what is returned form evaluate(...);
         *      - available moves: a 3d JSON array of legal moves for "side".
         *
         * If the type is "move", then a further fourth argument is required:
         *   - thinking time limit in seconds
         * In this case, a single JSON array is returned representing the
         * best move for "side".
         *
An example "eval" request:
$ ./chess_ai "RNBQKBNRPPPPPPPP                                pppppppprnbqkbnr" white eval
0 0 [[[0,1],[2,2]],[[0,1],[2,0]],[[0,6],[2,7]],[[0,6],[2,5]],[[1,0],[2,0]],[[1,0],[3,0]],[[1,1],[2,1]],[[1,1],[3,1]],[[1,2],[2,2]],[[1,2],[3,2]],[[1,3],[2,3]],[[1,3],[3,3]],[[1,4],[2,4]],[[1,4],[3,4]],[[1,5],[2,5]],[[1,5],[3,5]],[[1,6],[2,6]],[[1,6],[3,6]],[[1,7],[2,7 ]],[[1,7],[3,7]]]
An example "move" request:
$ ./chess_ai "RNBQKBNRPPPPPPPP                                pppppppprnbqkbnr" white move 9
         */
        static char piece_chars[7] = {' ','p','r','n','b','q','k'};
        //process board state string
        for (uint8_t i = 0; i < 64; i++){
            for (uint8_t j = 0; j < 7; j++){
                if ((IS_LOWER(argv[1][i]) ? argv[1][i] : CHANGE_CASE(argv[1][i])) == piece_chars[j]){
                    state.pieces[i/8][i%8] = j * (IS_LOWER(argv[1][i]) ? -1 : 1);
                }
            }
        }
        //process "side" argument
        int8_t side = !strcmp(argv[2], "white") ? WHITE : BLACK;
        //process request type
        if (!strcmp(argv[3], "eval")){ //evaluate
            printf("%s ", is_checkmated(&state, side) ? "1" : "0");
            printf("%d ", evaluate(&state));
            move_t moves[MAX_NUM_MOVES];
            uint8_t num_moves;
            num_moves = generate_moves(&state, side, moves);
            printf("[");
            for (uint8_t i = 0; i < num_moves; i++){
                printf("[[%d,%d],[%d,%d]]", moves[i].from[0],
                                            moves[i].from[1],
                                            moves[i].to[0],
                                            moves[i].to[1]);
                if (i != num_moves-1) printf(",");
            }
            printf("]\n");
        } else { //find best move
            uint8_t time_limit_s = str_to_int(argv[4]);
            move_t best_move = deepening_search(&state, side, time_limit_s);
            printf("[[%d,%d],[%d,%d]]\n", best_move.from[0],
                                          best_move.from[1],
                                          best_move.to[0],
                                          best_move.to[1]);
        }

    } else {

        ////////////////////////TERMINAL-BASED GAME/////////////////////////////////////////////

        //begin code for terminal-based chess game...

        move_t valid_user_moves[MAX_NUM_MOVES];
        uint8_t num_valid_user_moves;
        uint8_t users_move_is_valid = 0;

        //TODO: add ability to choose to play as black...
        //#define PLAYER_SIDE WHITE
        //if (PLAYER_SIDE == BLACK){
        //    ...
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

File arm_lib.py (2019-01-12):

import serial, os.path

"""
==Joe's Serial Protocol==
  Runs at a baud rate of 115200 pulses per second.
  The number of bytes in the message is sent first.
  The next byte represents the message type.
  The following number of enclosed bytes (NEBs) is dependent on the message type.
  First byte  | Message (type)  | NEBs | Enclosed bytes meaning
  0           | home            | 0    | N/A
  1           | motor state     | 1    | (0/1 => disable/enable)
  2           | set grabber     | 1    | (0/1 => grab off/grab on
  3           | move position   | 6    | (x: [0¬335, y: [100¬450], z: [0¬200])
                                          ^          ^             ^
       these uint16s (actually casted to signed) are sent *little-endian* (see INT_FROM_BYTES)

  Arduino will reply with a one byte code after every message.
  Value       | Meaning
  0           | Task completed as expected
  1           | x_pos has reached x_target - useful for timings
  2           | Invalid request structure (wrong NEBs)
  3           | Task failed due to invalid input ranges
  4           | Unkown request type

"""



LIMITS = {'x': (0, 335),
          'y': (100, 450),
          'z': (0, 200)}

class Arm():
    '''This class implements the necessary methods to communicate over serial
    with an Arduino that is running the corresponding "Joe's Serial Protocol"
    C++ code on.'''
    def __init__(self, port):
        '''Initialises an arm instance.
            - port <= serial port string'''
        self.port = port
        self._connect_to_arduino()
        self.serial.flushInput()
    def home(self):
        '''Moves the arm to its home position which is
        defined on the Arduino's side.'''
        self._write_and_check_success([1, 0])
    def set_motors(self, state):
        '''Enables or disables the stepper and servo motors on the arm.
            - state <= boolean: True=enable; False=disable'''
        self._write_and_check_success([2, 1, state])
    def set_grabber(self, state):
        '''Sets the state of the grabber on the arm's effector.
            - state <= boolean: True=grab on; False=grab off'''
        self._write_and_check_success([2, 2, state])
    def move_to(self, x, y, z):
        '''Moves the arm to the specified coordinate; given in millimeters.'''
        if not (LIMITS['x'][0] <= x <= LIMITS['x'][1] and \
                LIMITS['y'][0] <= y <= LIMITS['y'][1] and \
                LIMITS['z'][0] <= z <= LIMITS['z'][1]):
            raise ValueError('Position '+str([x,y,z])+' out of limits.')
        if not (type(x) == type(y) == type(z) == int):
            raise TypeError('Parameters: x,y,z must be integers!')
        self._write_and_check_success([7, 3,
                                       *self._bytes_from_int(x),
                                       *self._bytes_from_int(y),
                                       *self._bytes_from_int(z)])
    def block_till_reach_target(self):
        '''Waits till x_pos reaches next x_target. Blocking.'''
        r = self.serial.read()[0]
        if r != 1:
            raise Exception('Arduino return code != 1: '+ str(r))
    def _write_and_check_success(self, message):
        self.serial.flushInput()
        self.serial.write(message)
        r = self.serial.read()[0]
        if r != 0:
            raise Exception('Arduino code non-zero when sending: '+str(message)+ \
                            ', it replied with: '+str(r))
    def _connect_to_arduino(self):
        try:
            self.serial = serial.Serial(self.port, 115200);
        except serial.serialutil.SerialException:
            raise Exception('Could not open ['+self.port+'].')
    def _bytes_from_int(self, i):
        return (i >> 8, i & 0xff)

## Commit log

2017-10-15 updated main.py slightly and reversed output of recognise() in recognition
    [main.py, recognition.py]
2017-10-29 added arm.py
2018-08-21 old stls for base
    [Base v1.stl, Base v2.stl, Beam2 v2.stl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]
2018-08-21 added scads
    [base.scad, gripper.scad, link1.scad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]
2018-09-22 re-organise, going to try and finish web render today
    [Base v1.stl, Base v2.stl, Beam2 v2.stl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]
2018-12-28 back on it
    [bearing_plate.scad, bearing_plate.stl, belt_clamp.scad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]
2018-12-28 ... no, i am a noob, the solution was to use a linear track
2018-12-28 now millimeters, not centimeters
2018-12-28 detach not attach!
2018-12-28 no need to detach actually, MOSFET takes care of it anyway
2018-12-29 made acceleration for stepper
2018-12-29 swapped out map() for linear interpolation
    [sketch.ino]
2018-12-29 replaced map() with linear interpolation function
    [sketch.ino]
2018-12-30 more interpolation functions, but they're too slow, gonna try caching
    [sketch.ino]
2018-12-30 better communication with Arduino (error codes handled and a blocking function to wait till arrive at desired postition)
2018-12-30 small check-in as moving to raspberry pi
2019-01-03 spent ages fixing a stupid castling bug
    [main.c]
2019-01-04 rpi doesn't have python3.7 so no f-strings
    [main.py]
2019-01-05 updated servo offsets
2019-01-06 deepening search negamax wrapper and taken out castling as broken for now (will fix later)
    [main.c]
2019-01-06 servo offsets and home position
2019-01-12 bug in serial protocol; when 0xff recieved as lower byte in uin16_t, reading aborted, changed to sending the number of bytes first and no terminal bytes
    [arm_lib.py, sketch.ino]
2019-01-12 changed x-limit as was bit too high
    [arm_lib.py, sketch.ino]
2019-02-03 BIG CHANGES: removed castling as it caused many bugs. Fixed lots of other bugs - especially end-game checkmate stuff. Also started logging some ai_vs_ai games.
    [main.c]
2019-02-18 first full game; final bug at the end with failure to checkmate due to short-sightedness bug; fixed now
    [main.c, main.py, recognition.py]
